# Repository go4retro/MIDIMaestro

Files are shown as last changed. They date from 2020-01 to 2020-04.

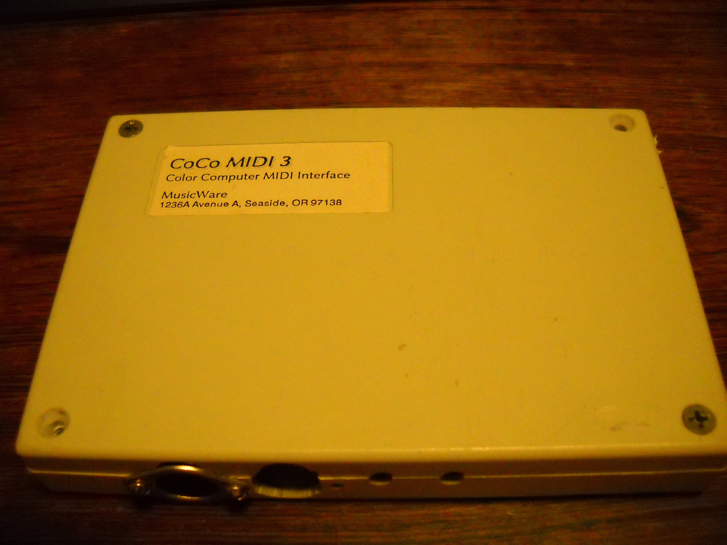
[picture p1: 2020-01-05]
ref/DSCN0303.JPG

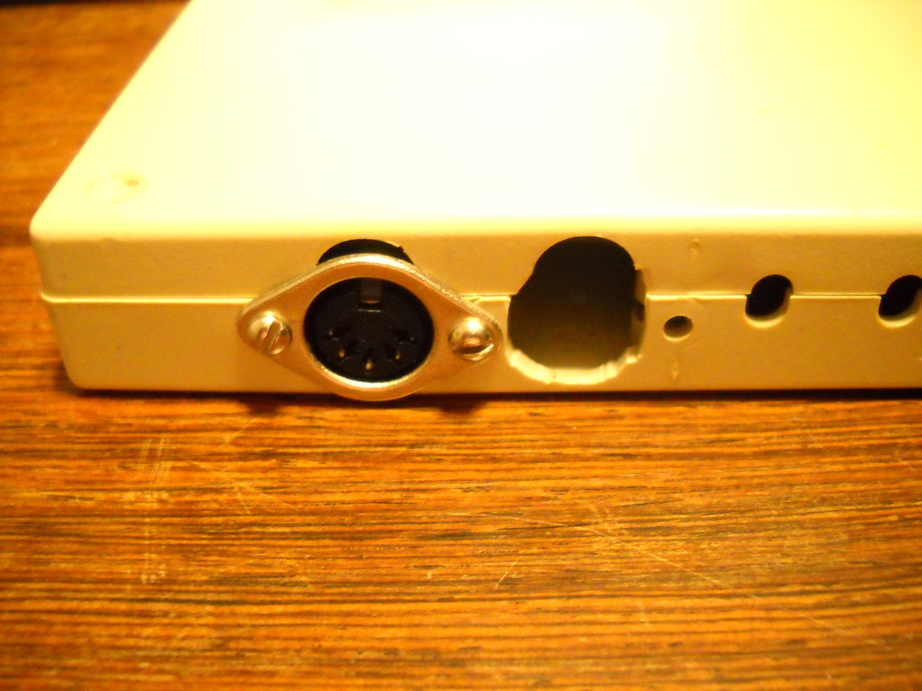
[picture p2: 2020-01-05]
ref/DSCN0304.JPG

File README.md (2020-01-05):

# TANDY Color Computer 1/2/3/Dragon MIDI Interface

V1 is a direct transcription of the original Rulaford MIDI interface design (that itself seems to be essentially a reference design used by almost all Motorola-bus systems of the day)

V2 switches out the 74ls90 for a 74ls161 counter (easier to source), but leaves the crystal design.  It also adds in some optional blinkenlights

V3 switches to a crystal oscillator and repurposes some of the now unused gates.

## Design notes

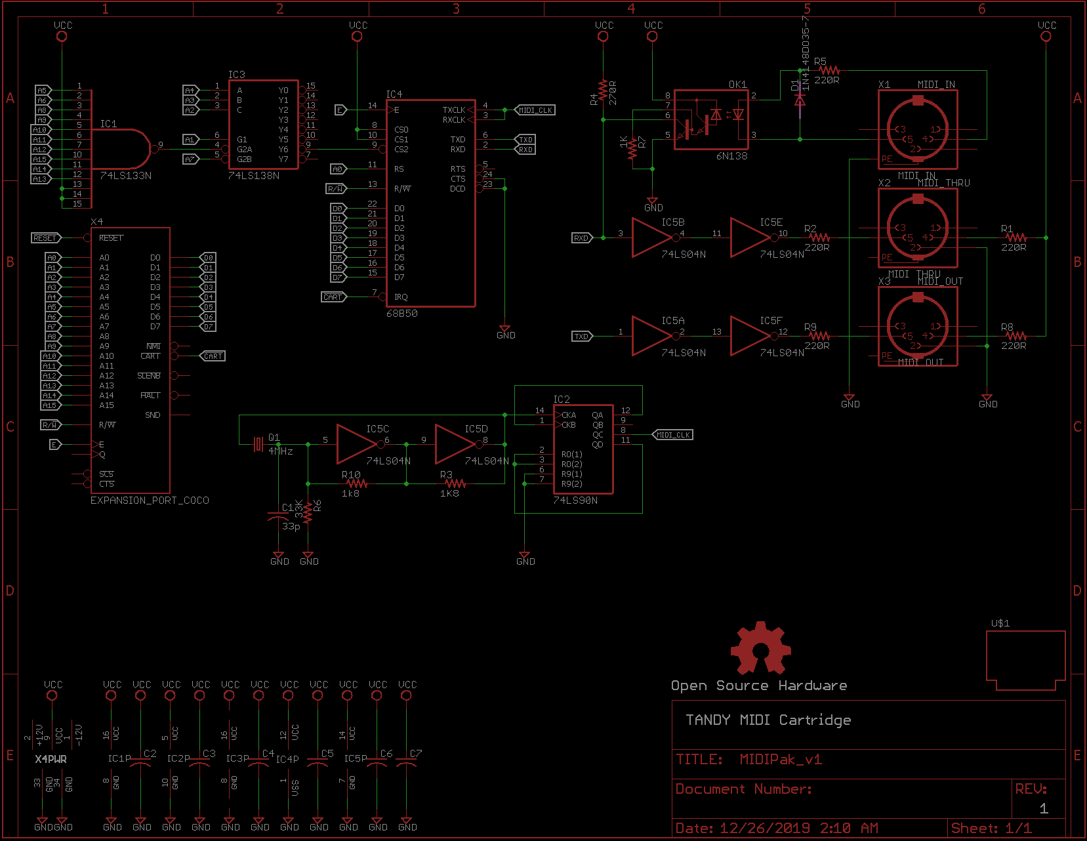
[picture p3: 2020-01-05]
pcb/MIDIMaestro v1 Schematic.png

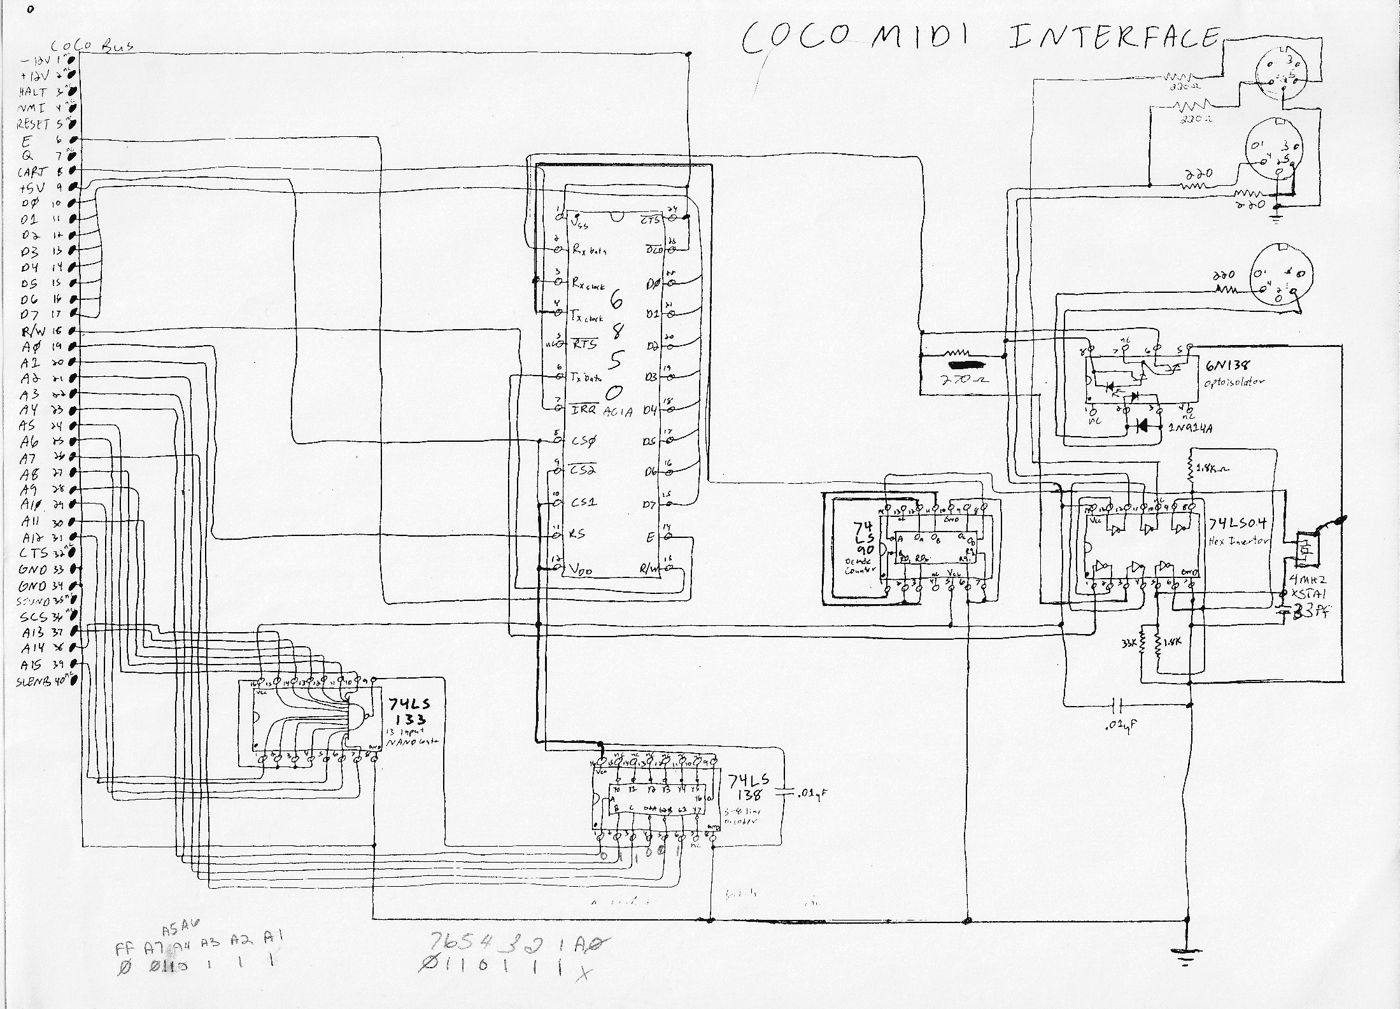
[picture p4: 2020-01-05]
ref/CoCoMIDI_Schematic.jpg

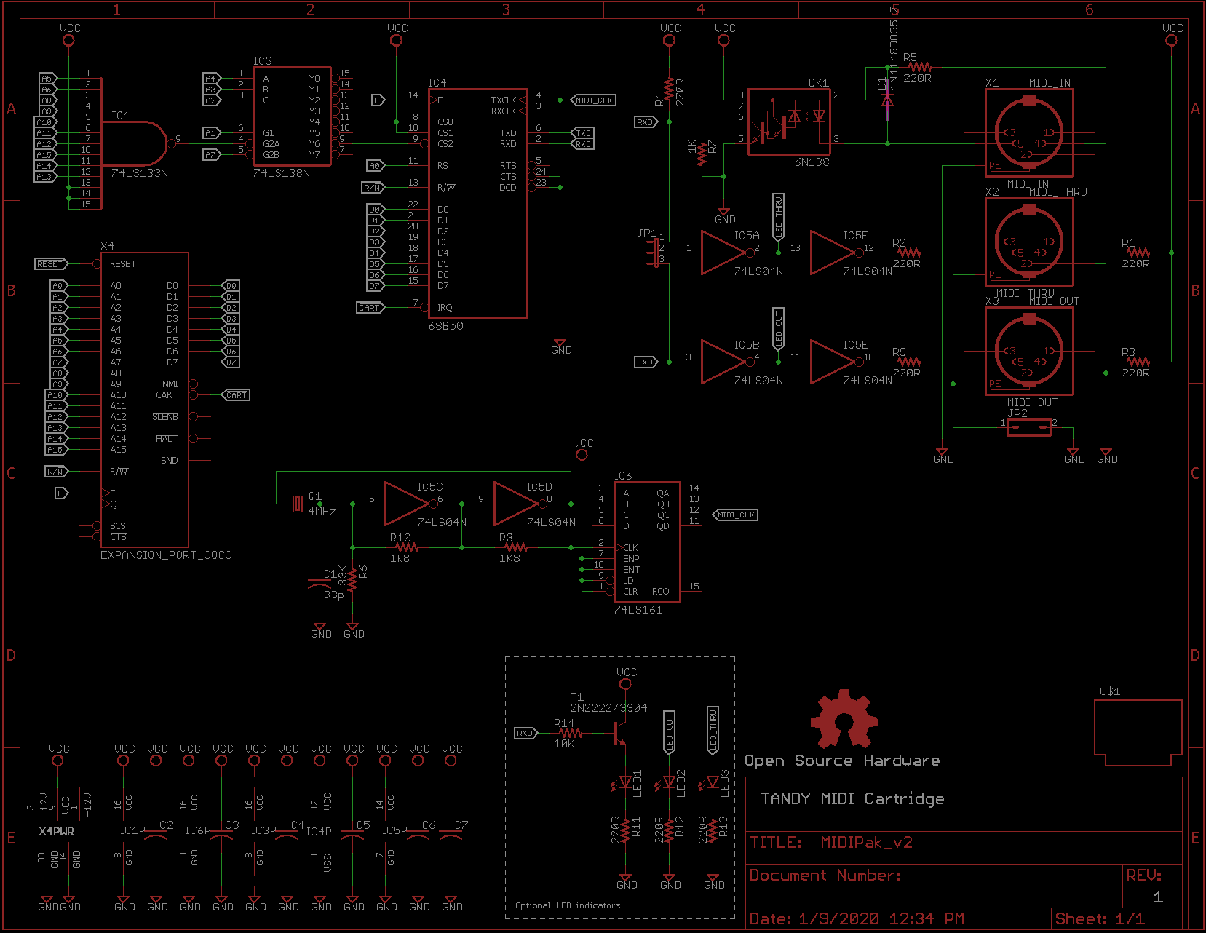
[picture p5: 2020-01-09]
pcb/MIDIMaestro v2 Schematic.png

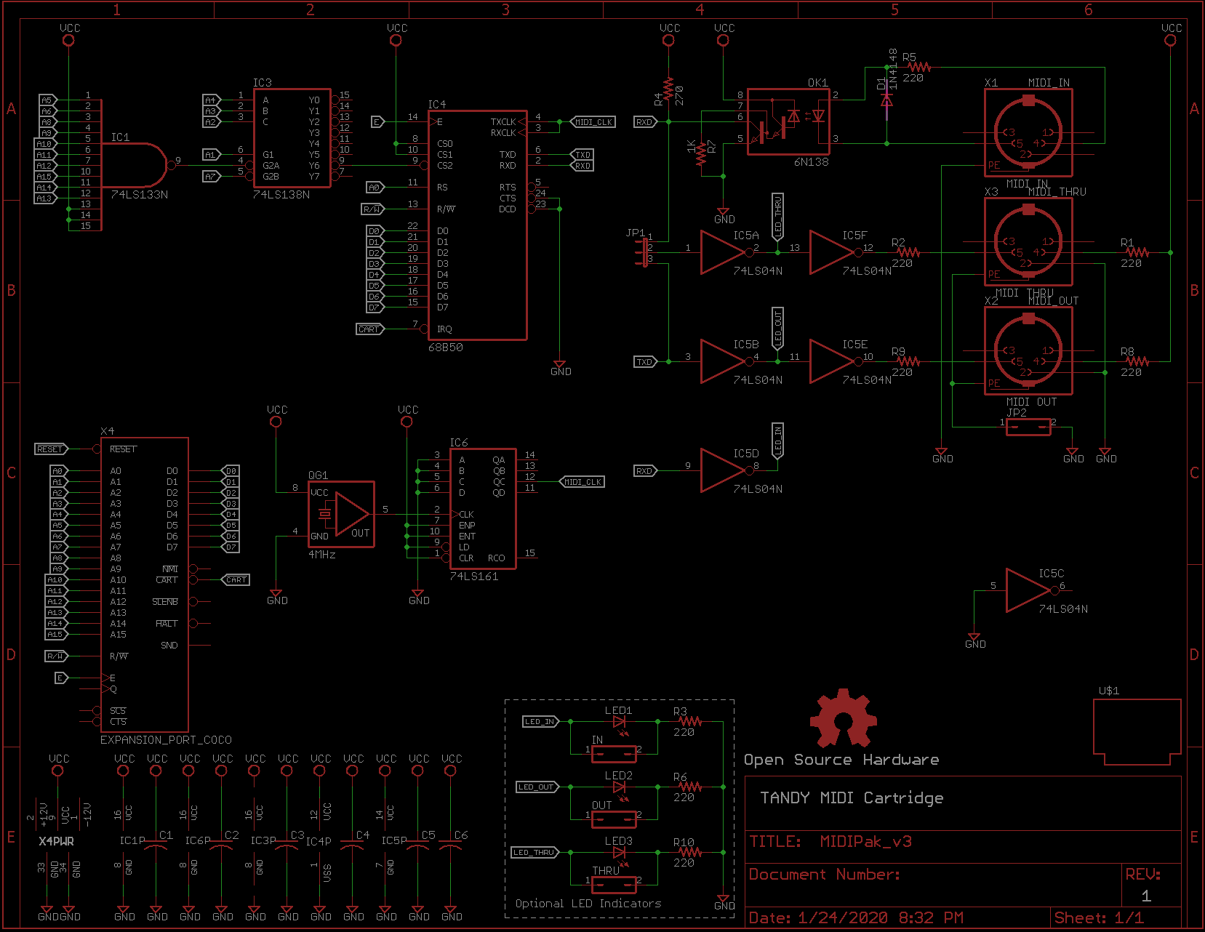
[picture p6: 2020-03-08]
pcb/MIDIMaestro v3 Schematic.png

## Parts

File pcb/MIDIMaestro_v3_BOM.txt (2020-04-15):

Parts	Qty	Value	Device	Description	Part number
"C1, C2, C3, C4, C5, C6"	6		C-US025-025X050	"CAPACITOR, American symbol"	BC3324-ND 
JP1	1		JP2E	JUMPER	EDJ1G0
JP2	1		JP1Q	JUMPER	EDJ1G0
JP3	1		JP1Q	JUMPER	EDJ1G0
LED1	1		LED3MM	LED	1080-1113-ND 
LED2	1		LED3MM	LED	1125-1182-ND 
LED3	1		LED3MM	LED	754-1220-ND 
R7	1	1K	R-US_0204/7	"RESISTOR, American symbol"	CF14JT1K00
D1	1	1N4148DO35-7	1N4148DO35-7	DIODE	1N4148-TPMSCT-ND 
"R1, R2, R3, R5, R6, R8, R9, R10"	8	220R	R-US_0204/7	"RESISTOR, American symbol"	CF14JT220R
R4	1	270R	R-US_0204/7	"RESISTOR, American symbol"	CF14JT270R
QG1	1	4MHz	QG5460	CRYSTAL RESONATOR	SG-531P 4.0000MC: ROHS
IC4	1	68B50	6850-RP	MICROCONTROLLER/MEMORY DEVICE	MC68B50
OK1	1	6N138	6N138	MOTOROLA OPTO COUPLER	160-1795-ND 
IC6	1	74*161	74160N	Synchronous 4-bit COUNTER	296-8244-5-ND 
IC5	1	74LS04N	74LS04N	Hex INVERTER	SN74HCT04N
IC1	1	74LS133N	74S133N	13-input NAND gate	74LS133
IC3	1	74LS138N	74LS138N	3-line to 8-line DECODER/DEMULTIPLEXER	SN74AHCT138N
"X1,X2,X3"	3	MIDI	MAB5SH	Female CONNECTOR	SDS-50J
	1	8 pin socket			2057-ICS-308-T-ND 
	1	14 pin socket			2057-ICS-314-T-ND 
	3	16 pin socket			2057-ICS-316-T-ND 
	1	"24 pin socket .6"""			2057-ICS-624-T-ND

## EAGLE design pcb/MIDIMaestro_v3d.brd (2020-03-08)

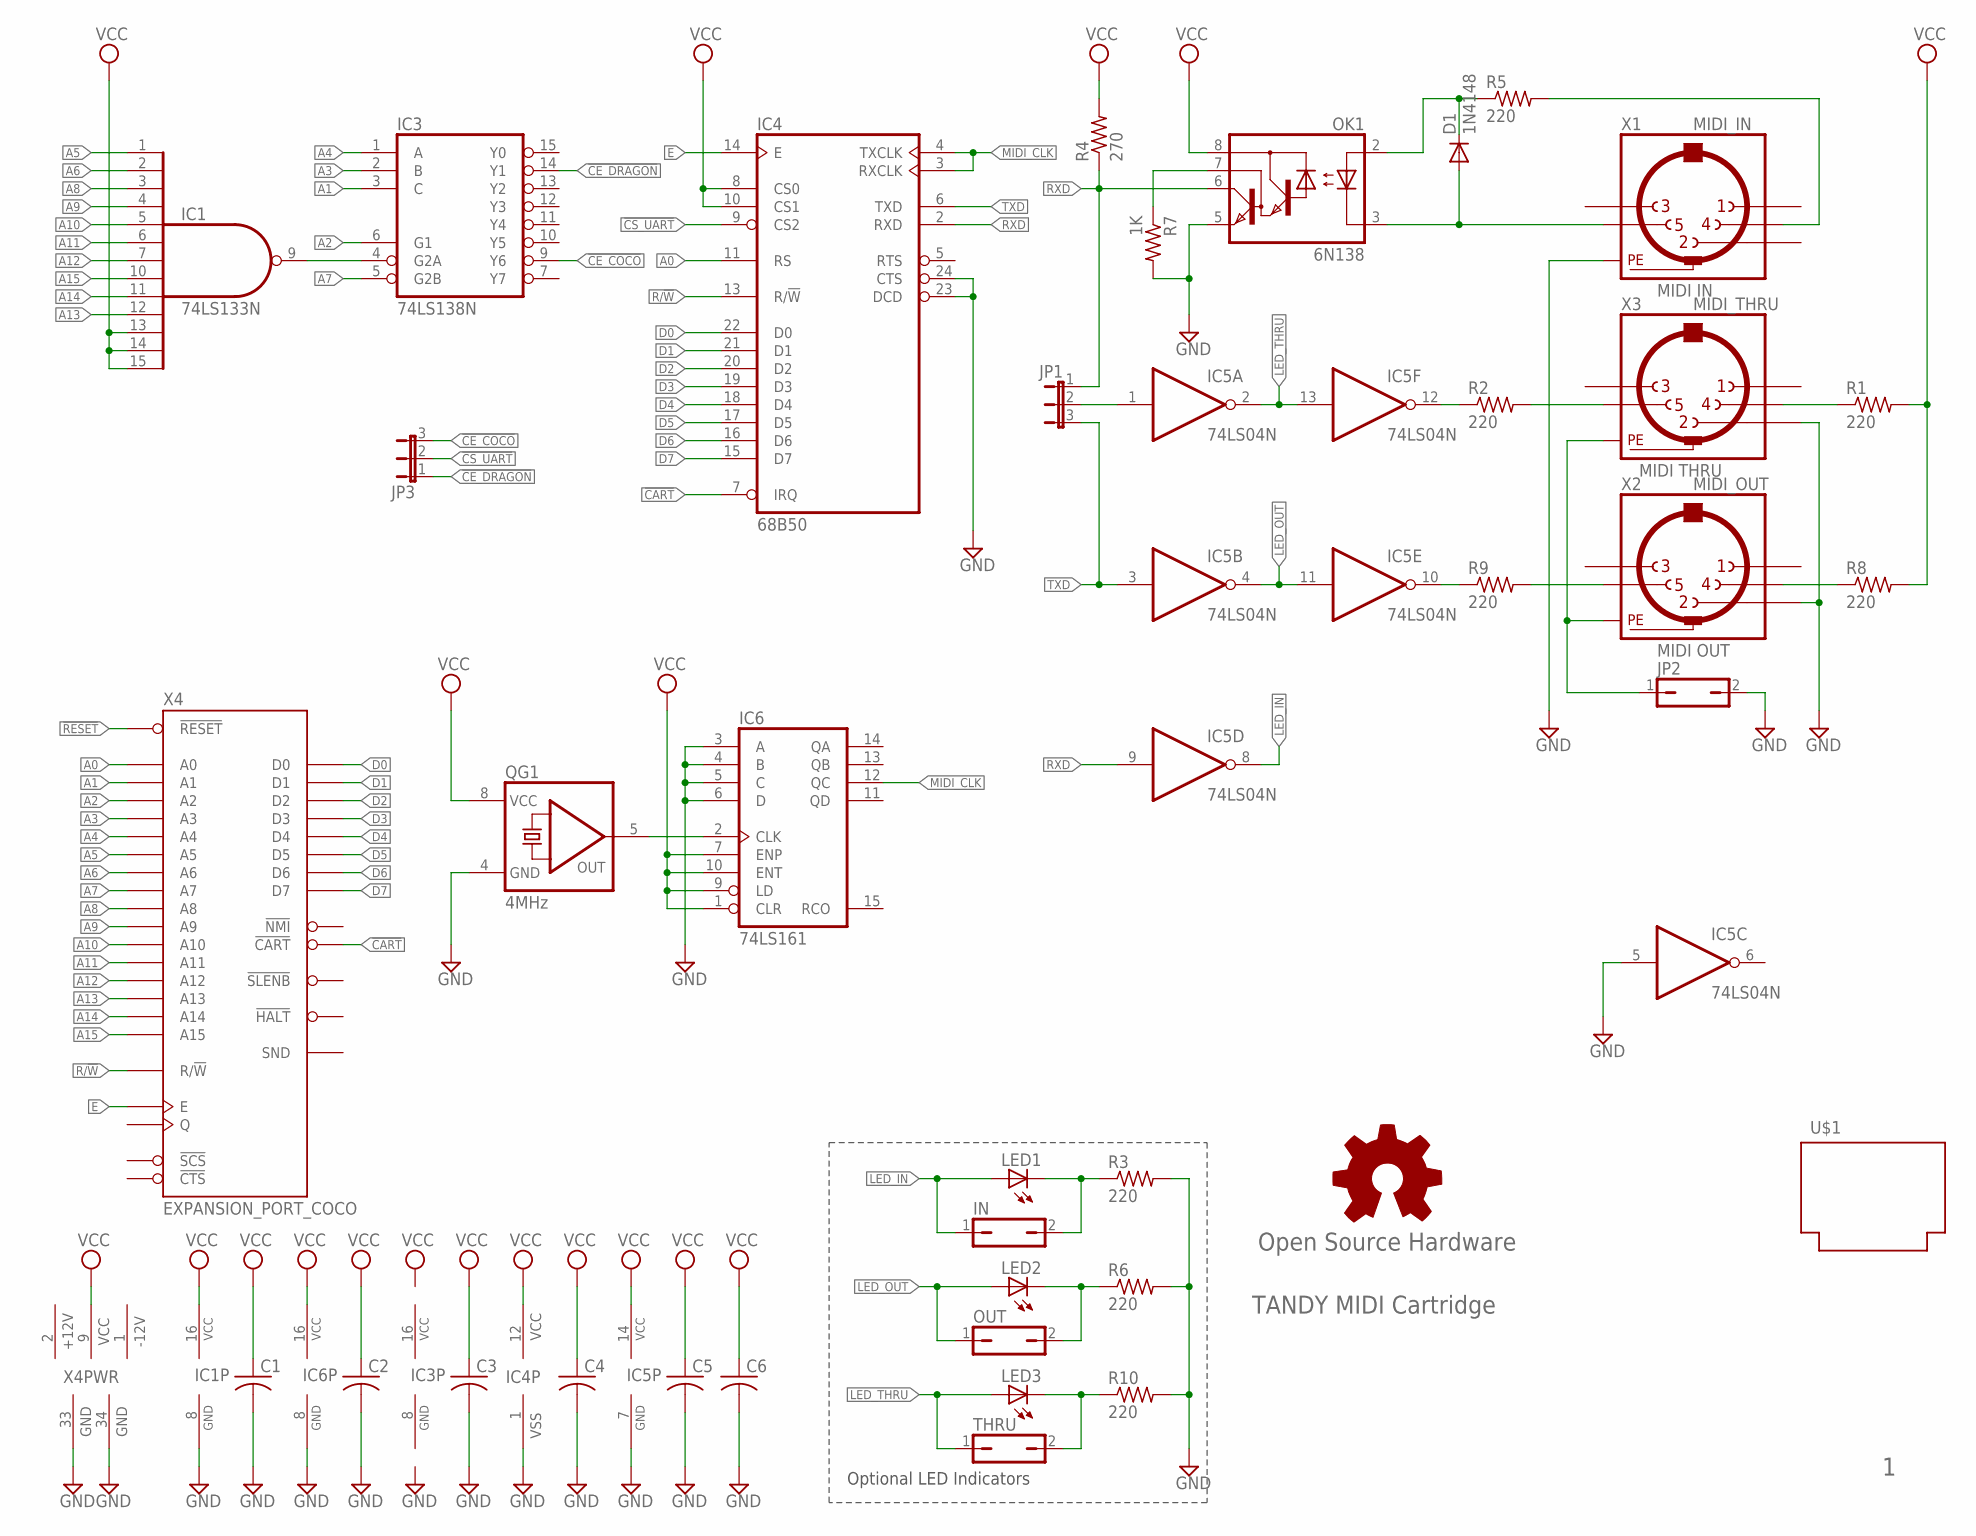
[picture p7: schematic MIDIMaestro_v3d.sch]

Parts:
C1, C2, C3, C4, C5, C6: C-US025-025X050; C025-025X050
D1: 1N4148; DO35-7
GOLD_ORB_SM1: Open Source Hardware; OSHW_8MM
IC1: 74LS133N; DIL16-RP
IC3: 74LS138N; DIL16-RP
IC4: 68B50; DIL24-ROUNDPAD
IC5: 74LS04N; DIL14-RP
IC6: 74LS161; DIL16-RP
IN: JP1Q; JP1
JP1, JP3: JP2E; JP2
JP2: JP1Q; JP1
LED1, LED2, LED3: LED3MM
OK1: 6N138; DIL08
OUT: JP1Q; JP1
QG1: 4MHz; DIL08S
R1, R2, R3, R5, R6, R8, R9, R10: 220; 0204/7
R4: 270; 0204/7
R7: 1K; 0204/7
THRU: JP1Q; JP1
U$1: PROGRAM_PAK
X1: MIDI_IN; MAB5SH
X2: MIDI_OUT; MAB5SH
X3: MIDI_THRU; MAB5SH
X4: EXPANSION_PORT_COCO; MA20-2

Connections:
!CART: IC4.7 (IRQ), X4.8 (!CART)
!CE_COCO: IC3.9 (Y6), JP3.3
!CE_DRAGON: IC3.14 (Y1), JP3.1
!CS_UART: IC4.9 (CS2), JP3.2
!RESET: X4.5 (!RESET)
+12V: X4.2 (+12V)
-12V: X4.1 (-12V)
A0: IC4.11 (RS), X4.19 (A0)
A1: IC3.3 (C), X4.20 (A1)
A2: IC3.6 (G1), X4.21 (A2)
A3: IC3.2 (B), X4.22 (A3)
A4: IC3.1 (A), X4.23 (A4)
A5: IC1.1 (I0), X4.24 (A5)
A6: IC1.2 (I1), X4.25 (A6)
A7: IC3.5 (G2B), X4.26 (A7)
A8: IC1.3 (I2), X4.27 (A8)
A9: IC1.4 (I3), X4.28 (A9)
A10: IC1.5 (I4), X4.29 (A10)
A11: IC1.6 (I5), X4.30 (A11)
A12: IC1.7 (I6), X4.31 (A12)
A13: IC1.12 (I9), X4.37 (A13)
A14: IC1.11 (I8), X4.38 (A14)
A15: IC1.10 (I7), X4.39 (A15)
D0: IC4.22 (D0), X4.10 (D0)
D1: IC4.21 (D1), X4.11 (D1)
D2: IC4.20 (D2), X4.12 (D2)
D3: IC4.19 (D3), X4.13 (D3)
D4: IC4.18 (D4), X4.14 (D4)
D5: IC4.17 (D5), X4.15 (D5)
D6: IC4.16 (D6), X4.16 (D6)
D7: IC4.15 (D7), X4.17 (D7)
E: IC4.14 (E), X4.6 (E)
GND: C1.2, C2.2, C3.2, C4.2, C5.2, C6.2, IC1.8 (GND), IC3.8 (GND), IC4.1 (VSS), IC4.23 (DCD), IC4.24 (CTS), IC5.5 (I), IC5.7 (GND), IC6.3 (A), IC6.4 (B), IC6.5 (C), IC6.6 (D), IC6.8 (GND), JP2.2, OK1.5 (GND), QG1.4 (GND), R3.2, R6.2, R7.2, R10.2, X1.PE, X1.PE@ (PE), X2.2, X3.2, X4.33 (GND), X4.34 (GND)
LED_IN: IC5.8 (O), IN.1, LED1.A
LED_OUT: IC5.4 (O), IC5.11 (I), LED2.A, OUT.1
LED_THRU: IC5.2 (O), IC5.13 (I), LED3.A, THRU.1
MIDI_CLK: IC4.3 (RXCLK), IC4.4 (TXCLK), IC6.12 (QC)
unnamed: R9.2, X2.5
unnamed: JP2.1, X2.PE, X2.PE@ (PE), X3.PE, X3.PE@ (PE)
unnamed: R8.1, X2.4
unnamed: IC5.10 (O), R9.1
unnamed: D1.C, OK1.2 (A), R5.1
unnamed: R5.2, X1.4
unnamed: D1.A, OK1.3 (C), X1.5
unnamed: OK1.7 (VB), R7.1
unnamed: R2.2, X3.5
unnamed: IC5.12 (O), R2.1
unnamed: IN.2, LED1.K (C), R3.1
unnamed: R1.1, X3.4
unnamed: IC1.9 (O), IC3.4 (G2A)
unnamed: IC6.2 (CLK), QG1.5 (OUT)
unnamed: IC5.1 (I), JP1.2
unnamed: LED2.K (C), OUT.2, R6.1
unnamed: LED3.K (C), R10.1, THRU.2
R/!W: IC4.13 (R/!W), X4.18 (R/!W)
RXD: IC4.2 (RXD), IC5.9 (I), JP1.1, OK1.6 (VO), R4.1
TXD: IC4.6 (TXD), IC5.3 (I), JP1.3
VCC: C1.1, C2.1, C3.1, C4.1, C5.1, C6.1, IC1.13 (I10), IC1.14 (I11), IC1.15 (I12), IC1.16 (VCC), IC3.16 (VCC), IC4.8 (CS0), IC4.10 (CS1), IC4.12 (VCC), IC5.14 (VCC), IC6.1 (CLR), IC6.7 (ENP), IC6.9 (LD), IC6.10 (ENT), IC6.16 (VCC), OK1.8 (VCC), QG1.8 (VCC), R1.2, R4.2, R8.2, X4.9 (VCC)

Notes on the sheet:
TANDY MIDI Cartridge
MIDI OUT
MIDI IN
MIDI THRU
Optional LED Indicators

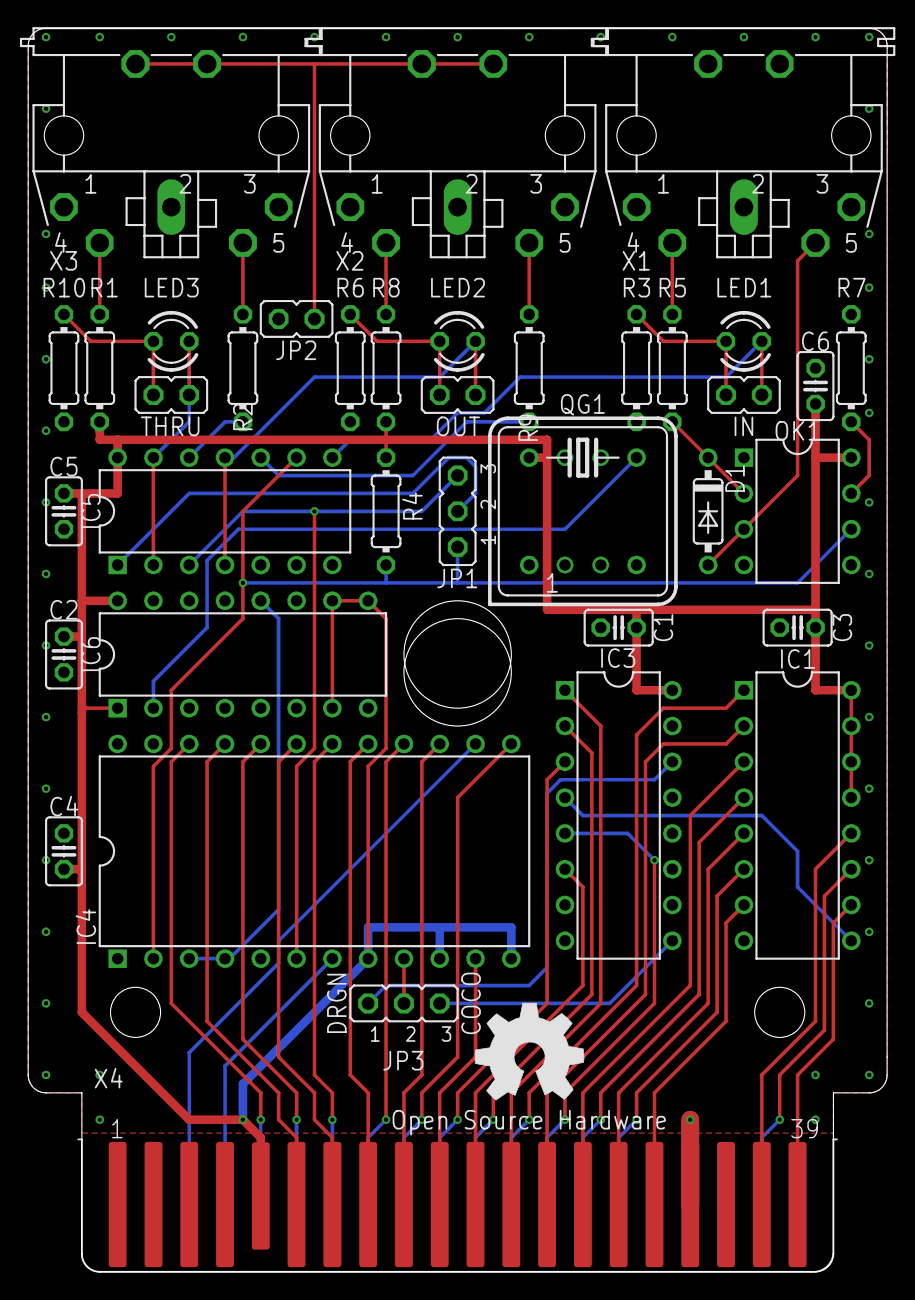
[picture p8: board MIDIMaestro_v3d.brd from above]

Board: 2 copper layers, 61.0 x 88.3 mm, 39 parts (0 on the bottom side), 55 nets.

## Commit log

2020-01-09 Fixed polarity issues with LED signals
    [MIDIPak_v2.brd, MIDIPak_v2.sch, MIDIPak_v3.brd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]
2020-01-11 Cart port connector was slightly narrow. Widened.
    [MIDIPak_v1.brd, MIDIPak_v1.sch, MIDIPak_v2.brd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]
2020-03-08 Changed name, Added Dragon variant
    [MIDIMaestro_v1.brd, MIDIMaestro_v1.sch, MIDIMaestro_v2.brd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]
2020-03-08 Add PNG opf V3 Dragon Schematic
2020-04-15 Added other BOM formats
    [MIDIMaestro_v3_BOM.csv]
2020-04-15 Cleaned up alternate BOM formats
    [MIDIMaestro_v3_BOM.csv]
